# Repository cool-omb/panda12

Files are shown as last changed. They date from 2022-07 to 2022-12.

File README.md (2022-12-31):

# panda12

## 概要 Overview

Bluetooth 接続の 12 キーキーボード。

キーマップの変更等がWiFi経由で出来る。

## 使い方 Usage
### キーボード使用時
スライドスイッチで電源を入れ、 `Test_keyboard` にBluetooth接続する。
### キーマップ設定時
設定ボタンを押しながら電源を入れ、 `Preference_keyboard` にWiFi接続する。
ブラウザからキーマップを変更後、 `保存` ボタンをクリックすることで変更が反映される。

※ 有線LANを接続しているデバイスからは、キーマップ変更ページへ自動で遷移しないことがあるので、 `192.168.4.1` へ手動でアクセスしてください。

## 必要要件 Requirement

- KiCad 6.0.10

  - [Kailh socket MX footprint](https://github.com/daprice/keyswitches.pretty)

- [Arduino IDE 2.0.3](https://www.arduino.cc/en/software)
  - [Arduino core for the ESP32 v2.0.4](https://github.com/espressif/arduino-esp32#installation-instructions)
  - [NimBLE-Arduino v1.4.0](https://github.com/h2zero/NimBLE-Arduino)
  - [ESP32-NimBLE-Keyboard v1.4.0](https://github.com/wakwak-koba/ESP32-NimBLE-Keyboard)
  - [arduino-esp8266fs-plugin v0.5.0](https://github.com/esp8266/arduino-esp8266fs-plugin)
  - [Arduino ESP32 filesystem uploader v1.0](https://github.com/me-no-dev/arduino-esp32fs-plugin)
  - [ESP8266_Spiram](https://github.com/Gianbacchio/ESP8266_Spiram)
  - [ESPAsyncWebServer](https://github.com/me-no-dev/ESPAsyncWebServer)
  - [ArduinoJson](https://github.com/bblanchon/ArduinoJson)

## 注意事項 Note
- BLE通信の安定性は上記のライブラリに依存しており、通信するデバイスによっては動作が不安定になることもございます。
- `Blekeyboard.print()` の挙動が不安定で、これを利用しているテキスト出力もまた安定的に動作しません。

## 参考 Reference

- [CaptivePortalExample](https://github.com/elliotmade/ESP32-Captive-Portal-Example/blob/test/src/main.cpp)

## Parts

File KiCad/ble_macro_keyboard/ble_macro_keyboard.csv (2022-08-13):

Source: | \\wsl.localhost\Ubuntu\home\krkrkrrn\workspace\ble-macro-keyboard\KiCad\ble_macro_keyboard\ble_macro_keyboard.kicad_sch
Date: | 2022/08/08 6:19:14
Tool: | Eeschema (6.0.6)
Generator: | C:\Program Files\KiCad\6.0\bin\scripting\plugins/bom_csv_grouped_by_value.py
Component Count: | 34
Individual Components:
Item | Qty | Reference(s) | Value | LibPart | Footprint | Datasheet | Description | Field4 | Field5 | Field6 | Field7 | Height | MANUFACTURER | Manufacturer_Name | Manufacturer_Part_Number | Mouser Part Number | Mouser Price/Stock | PARTREV
 |  | C1 | 0.01u | Device:C | Capacitor_SMD:C_0603_1608Metric_Pad1.08x0.95mm_HandSolder | ~
 |  | C2 | 0.01u | Device:C | Capacitor_SMD:C_0603_1608Metric_Pad1.08x0.95mm_HandSolder | ~
 |  | C3 | 1u | Device:C | Capacitor_SMD:C_0603_1608Metric_Pad1.08x0.95mm_HandSolder | ~
 |  | C4 | 1u | Device:C | Capacitor_SMD:C_0603_1608Metric_Pad1.08x0.95mm_HandSolder | ~
 |  | C5 | 4.7u | Device:C | Capacitor_THT:CP_Radial_D5.0mm_P2.00mm | ~
 |  | C6 | 10u | Device:C | Capacitor_THT:CP_Radial_D5.0mm_P2.00mm | ~
 |  | D1 | LED | Device:LED | LED_THT:LED_D3.0mm | ~
 |  | D2 | LED_RKBG | Device:LED_RKBG | LED_THT:LED_D5.0mm-4_RGB | ~
 |  | IC1 | ADP3338AKCZ-3.3-RL | ble_keyboard:ADP3338AKCZ-3.3-RL | Ble_keyboard:SOT230P700X180-4N | http://www.analog.com/media/en/technical-documentation/data-sheets/ADP3338.pdf | LDO Voltage Regulator anyCAP 1A SOT223-3 Analog Devices ADP3338AKCZ-3.3-RL, LDO Voltage Regulator, 1.6A, 3.3 V +/-0.8%, 2.7 8 Vin, 3 + Tab-Pin SOT-223 |  |  |  |  | 1.8 |  | Analog Devices | ADP3338AKCZ-3.3-RL | 584-ADP3338AKCZ3.3R | https://www.mouser.co.uk/ProductDetail/Analog-Devices/ADP3338AKCZ-33-RL?qs=WIvQP4zGangPtIg4n%252B1tTA%3D%3D
 |  | J1 | Conn_01x03_Male | Connector:Conn_01x03_Male | Ble_keyboard:JST_SHL_SM03B-SHLS-TF_1x03-1MP_P1.00mm_Horizontal | ~
 |  | Q1 | IRLML6402 | Transistor_FET:IRLML6402 | Package_TO_SOT_SMD:SOT-23 | https://www.infineon.com/dgdl/irlml6402pbf.pdf?fileId=5546d462533600a401535668d5c2263c
 |  | R1 | 10 | Device:R | Resistor_SMD:R_0603_1608Metric_Pad1.05x0.95mm_HandSolder | ~
 |  | R2 | 10 | Device:R | Resistor_SMD:R_0603_1608Metric_Pad1.05x0.95mm_HandSolder | ~
 |  | R3 | 10 | Device:R | Resistor_SMD:R_0603_1608Metric_Pad1.05x0.95mm_HandSolder | ~
 |  | R4 | 47 | Device:R | Resistor_SMD:R_0603_1608Metric_Pad1.05x0.95mm_HandSolder | ~
 |  | R5 | 470 | Device:R | Resistor_SMD:R_0603_1608Metric_Pad1.05x0.95mm_HandSolder | ~
 |  | R6 | 2k | Device:R | Resistor_SMD:R_0603_1608Metric_Pad1.05x0.95mm_HandSolder | ~
 |  | R7 | 100k | Device:R | Resistor_SMD:R_0603_1608Metric_Pad1.05x0.95mm_HandSolder | ~
 |  | SW1 | SW_SPDT | Switch:SW_SPDT | Ble_keyboard:SW_Slide_SPDT_MSK-12C02 | ~
 |  | SW2 | SW_Push | Switch:SW_Push | Ble_keyboard:SW_Push_Dual_x2_TS-4401 | ~
 |  | SW3 | SW_Push | Switch:SW_Push | Keyswitches:Kailh_socket_MX | ~
 |  | SW4 | SW_Push | Switch:SW_Push | Keyswitches:Kailh_socket_MX | ~
 |  | SW5 | SW_Push | Switch:SW_Push | Keyswitches:Kailh_socket_MX | ~
 |  | SW6 | SW_Push | Switch:SW_Push | Keyswitches:Kailh_socket_MX | ~
 |  | SW7 | SW_Push | Switch:SW_Push | Keyswitches:Kailh_socket_MX | ~
 |  | SW8 | SW_Push | Switch:SW_Push | Keyswitches:Kailh_socket_MX | ~
 |  | SW9 | SW_Push | Switch:SW_Push | Keyswitches:Kailh_socket_MX | ~
 |  | SW10 | SW_Push | Switch:SW_Push | Keyswitches:Kailh_socket_MX | ~
 |  | SW11 | SW_Push | Switch:SW_Push | Keyswitches:Kailh_socket_MX | ~
 |  | SW12 | SW_Push | Switch:SW_Push | Keyswitches:Kailh_socket_MX | ~
 |  | SW13 | SW_Push | Switch:SW_Push | Keyswitches:Kailh_socket_MX | ~
 |  | SW14 | SW_Push | Switch:SW_Push | Keyswitches:Kailh_socket_MX | ~
 |  | U1 | MCP73831T-2ACI_OT | ble_keyboard:MCP73831T-2ACI_OT | Ble_keyboard:SOT95P280X145-5N | 56K7045 |  | 1332158 | MCP73831T-2ACI/OT | Microchip | SOT-5
 |  | U2 | ESP32-DEVKITC-32D | ESP32-DEVKITC-32D:ESP32-DEVKITC-32D | Evaluation_board:MODULE_ESP32-DEVKITC-32D |  |  |  |  |  |  |  | Espressif Systems |  |  |  |  | 4
Collated Components:
Item | Qty | Reference(s) | Value | LibPart | Footprint | Datasheet | Description | Field4 | Field5 | Field6 | Field7 | Height | MANUFACTURER | Manufacturer_Name | Manufacturer_Part_Number | Mouser Part Number | Mouser Price/Stock | PARTREV
1 | 2 | C1, C2 | 0.01u | Device:C | Capacitor_SMD:C_0603_1608Metric_Pad1.08x0.95mm_HandSolder | ~
2 | 2 | C3, C4 | 1u | Device:C | Capacitor_SMD:C_0603_1608Metric_Pad1.08x0.95mm_HandSolder | ~
3 | 1 | C5 | 4.7u | Device:C | Capacitor_THT:CP_Radial_D5.0mm_P2.00mm | ~
4 | 1 | C6 | 10u | Device:C | Capacitor_THT:CP_Radial_D5.0mm_P2.00mm | ~
5 | 1 | D1 | LED | Device:LED | LED_THT:LED_D3.0mm | ~
6 | 1 | D2 | LED_RKBG | Device:LED_RKBG | LED_THT:LED_D5.0mm-4_RGB | ~
7 | 1 | IC1 | ADP3338AKCZ-3.3-RL | ble_keyboard:ADP3338AKCZ-3.3-RL | Ble_keyboard:SOT230P700X180-4N | http://www.analog.com/media/en/technical-documentation/data-sheets/ADP3338.pdf | LDO Voltage Regulator anyCAP 1A SOT223-3 Analog Devices ADP3338AKCZ-3.3-RL, LDO Voltage Regulator, 1.6A, 3.3 V +/-0.8%, 2.7 8 Vin, 3 + Tab-Pin SOT-223 |  |  |  |  | 1.8 |  | Analog Devices | ADP3338AKCZ-3.3-RL | 584-ADP3338AKCZ3.3R | https://www.mouser.co.uk/ProductDetail/Analog-Devices/ADP3338AKCZ-33-RL?qs=WIvQP4zGangPtIg4n%252B1tTA%3D%3D
8 | 1 | J1 | Conn_01x03_Male | Connector:Conn_01x03_Male | Ble_keyboard:JST_SHL_SM03B-SHLS-TF_1x03-1MP_P1.00mm_Horizontal | ~
9 | 1 | Q1 | IRLML6402 | Transistor_FET:IRLML6402 | Package_TO_SOT_SMD:SOT-23 | https://www.infineon.com/dgdl/irlml6402pbf.pdf?fileId=5546d462533600a401535668d5c2263c
10 | 3 | R1, R2, R3 | 10 | Device:R | Resistor_SMD:R_0603_1608Metric_Pad1.05x0.95mm_HandSolder | ~
11 | 1 | R4 | 47 | Device:R | Resistor_SMD:R_0603_1608Metric_Pad1.05x0.95mm_HandSolder | ~
12 | 1 | R5 | 470 | Device:R | Resistor_SMD:R_0603_1608Metric_Pad1.05x0.95mm_HandSolder | ~
13 | 1 | R6 | 2k | Device:R | Resistor_SMD:R_0603_1608Metric_Pad1.05x0.95mm_HandSolder | ~
14 | 1 | R7 | 100k | Device:R | Resistor_SMD:R_0603_1608Metric_Pad1.05x0.95mm_HandSolder | ~
15 | 1 | SW1 | SW_SPDT | Switch:SW_SPDT | Ble_keyboard:SW_Slide_SPDT_MSK-12C02 | ~
16 | 1 | SW2 | SW_Push | Switch:SW_Push | Ble_keyboard:SW_Push_Dual_x2_TS-4401 | ~
17 | 12 | SW3, SW4, SW5, SW6, SW7, SW8, SW9, SW10, SW11, SW12, SW13, SW14 | SW_Push | Switch:SW_Push | Keyswitches:Kailh_socket_MX | ~
18 | 1 | U1 | MCP73831T-2ACI_OT | ble_keyboard:MCP73831T-2ACI_OT | Ble_keyboard:SOT95P280X145-5N | 56K7045 |  | 1332158 | MCP73831T-2ACI/OT | Microchip | SOT-5
19 | 1 | U2 | ESP32-DEVKITC-32D | ESP32-DEVKITC-32D:ESP32-DEVKITC-32D | Evaluation_board:MODULE_ESP32-DEVKITC-32D |  |  |  |  |  |  |  | Espressif Systems |  |  |  |  | 4

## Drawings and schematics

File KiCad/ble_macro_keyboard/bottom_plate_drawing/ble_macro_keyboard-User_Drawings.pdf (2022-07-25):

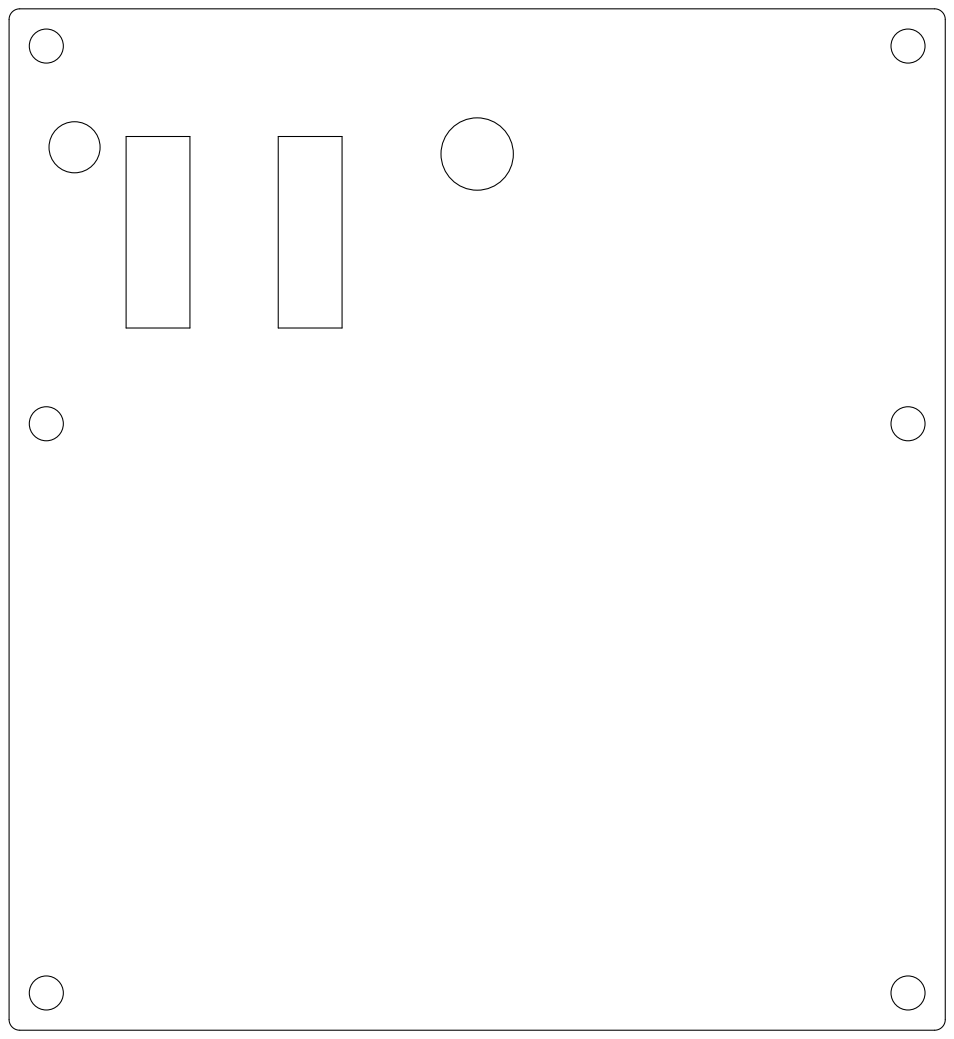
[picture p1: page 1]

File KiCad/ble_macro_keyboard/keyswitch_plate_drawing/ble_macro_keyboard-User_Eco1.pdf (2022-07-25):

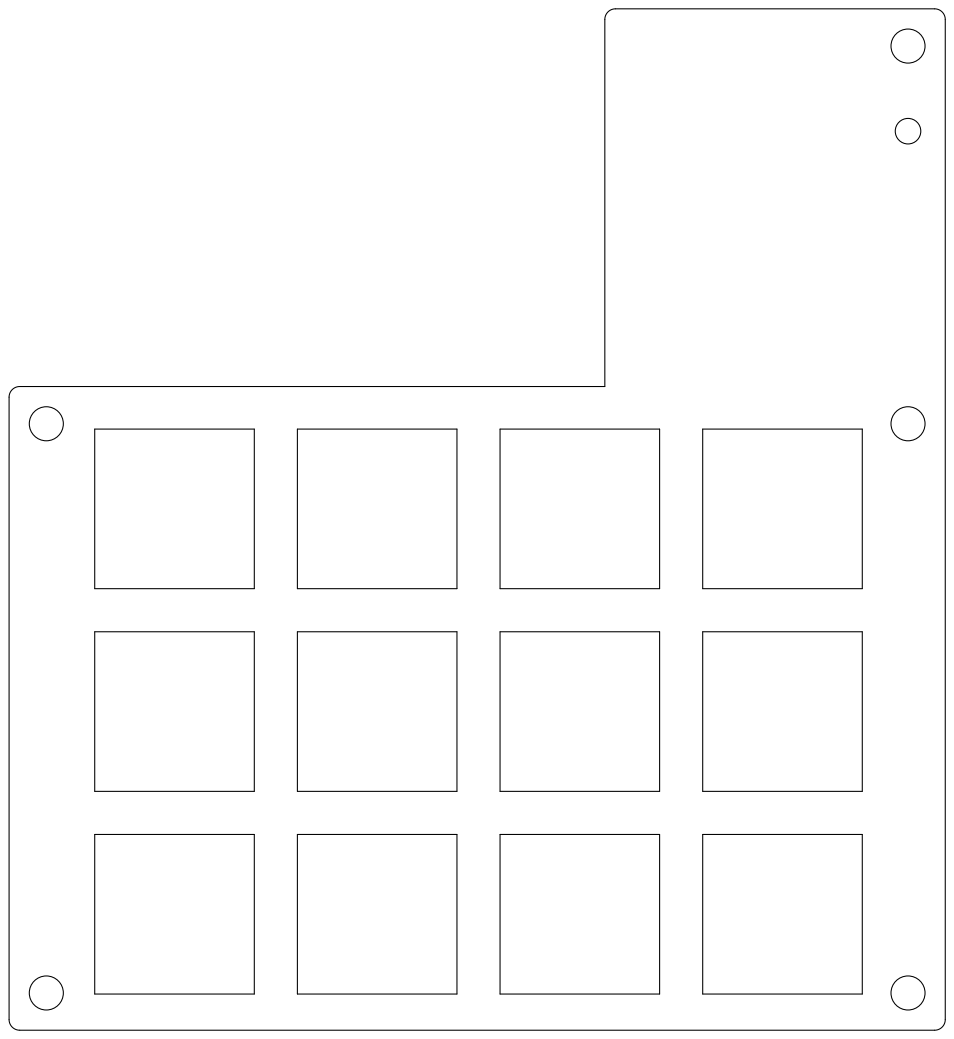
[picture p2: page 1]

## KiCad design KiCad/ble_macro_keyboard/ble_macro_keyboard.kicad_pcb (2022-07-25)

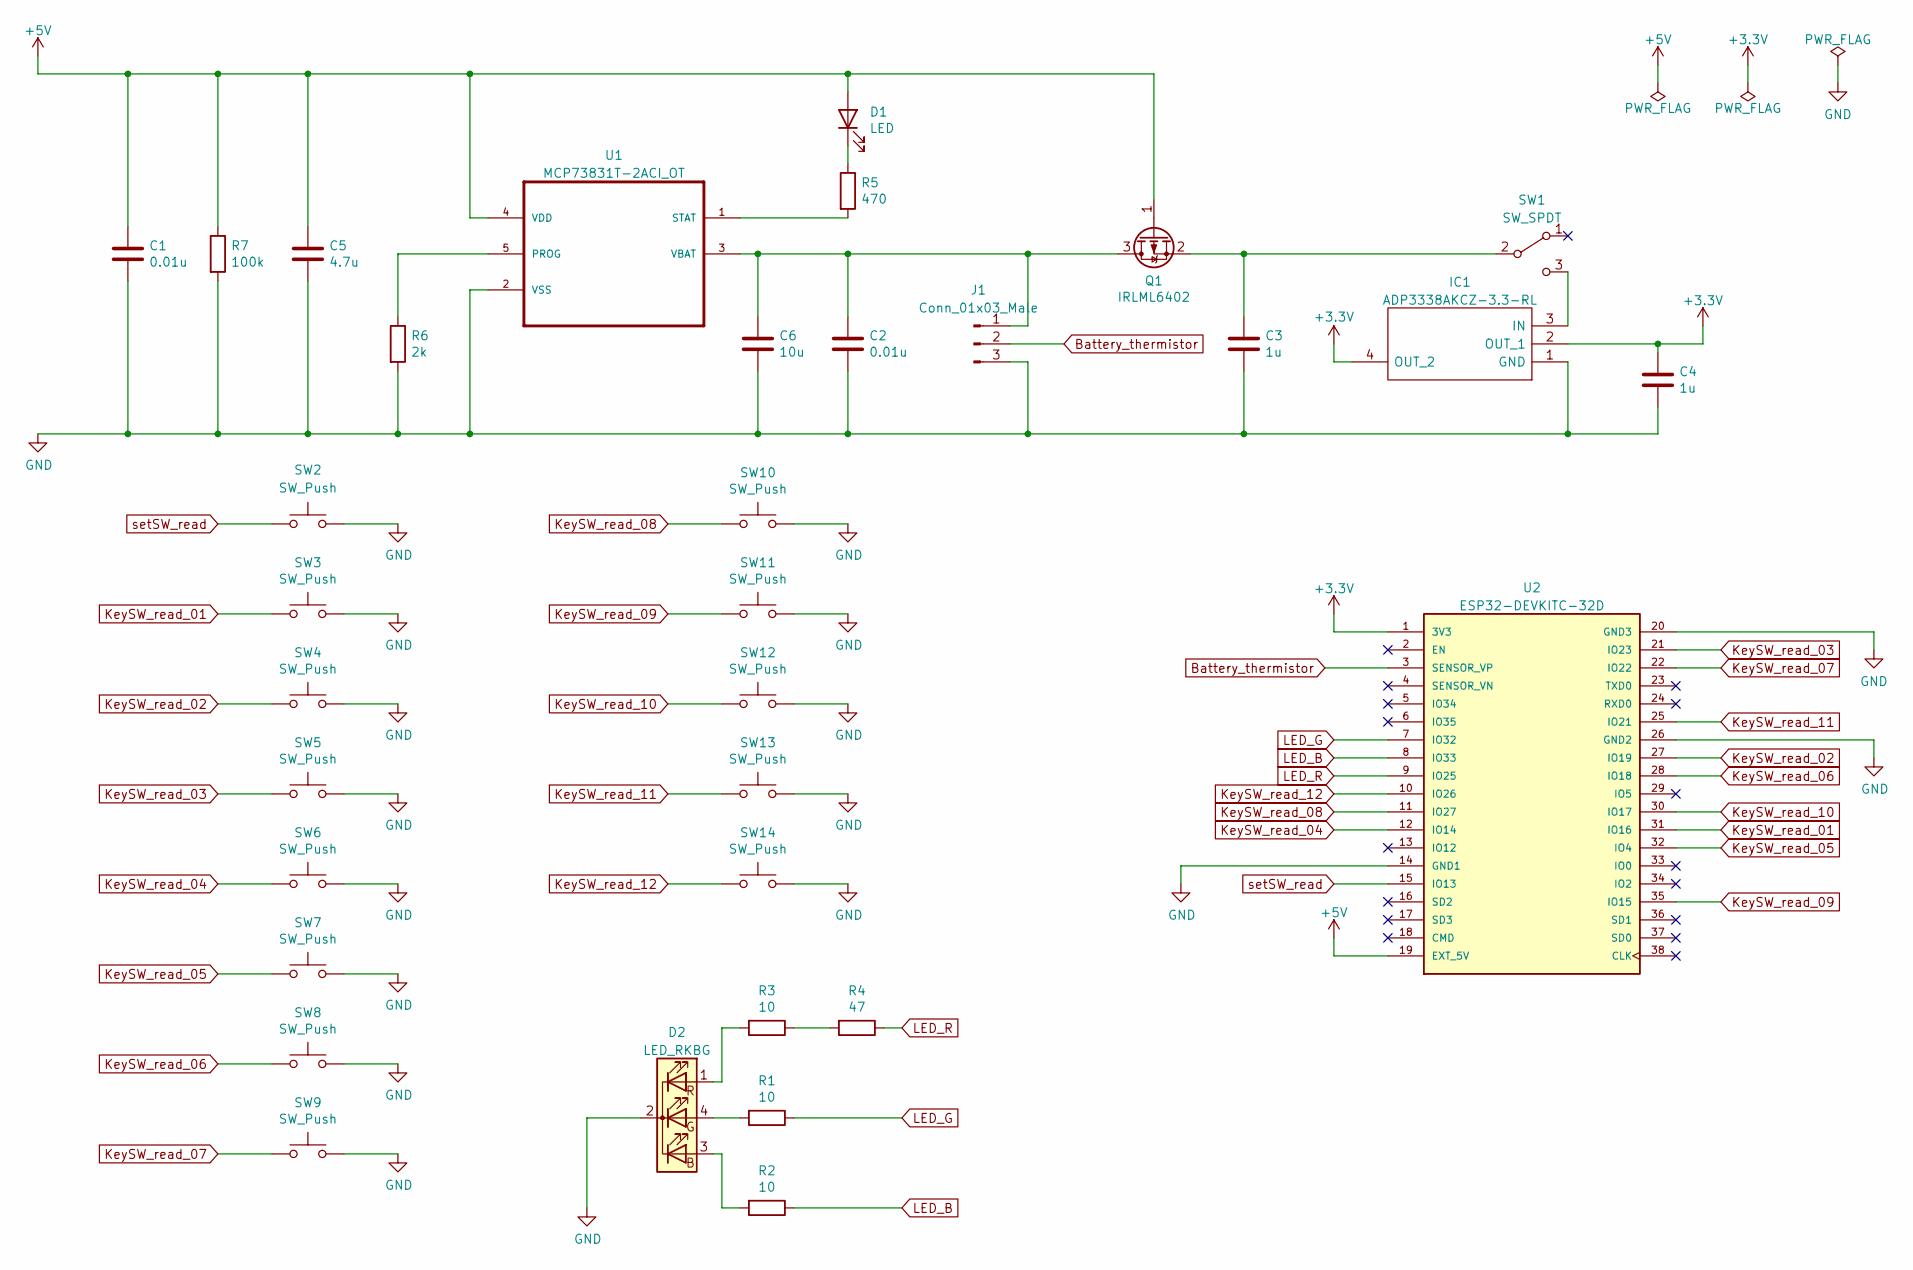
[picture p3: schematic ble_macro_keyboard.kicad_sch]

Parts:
C1, C2: 0.01u; C_0603_1608Metric_Pad1.08x0.95mm_HandSolder
C3, C4: 1u; C_0603_1608Metric_Pad1.08x0.95mm_HandSolder
C5: 4.7u; CP_Radial_D5.0mm_P2.00mm
C6: 10u; CP_Radial_D5.0mm_P2.00mm
D1: LED; LED_D3.0mm
D2: LED_RKBG; LED_D5.0mm-4_RGB
IC1: ADP3338AKCZ-3.3-RL; SOT230P700X180-4N; Mouser Part Number 584-ADP3338AKCZ3.3R
J1: Conn_01x03_Male; JST_SHL_SM03B-SHLS-TF_1x03-1MP_P1.00mm_Horizontal
Q1: IRLML6402; SOT-23
R1, R2, R3: 10; R_0603_1608Metric_Pad1.05x0.95mm_HandSolder
R4: 47; R_0603_1608Metric_Pad1.05x0.95mm_HandSolder
R5: 470; R_0603_1608Metric_Pad1.05x0.95mm_HandSolder
R6: 2k; R_0603_1608Metric_Pad1.05x0.95mm_HandSolder
R7: 100k; R_0603_1608Metric_Pad1.05x0.95mm_HandSolder
SW1: SW_SPDT; SW_Slide_SPDT_MSK-12C02
SW2: SW_Push; SW_Push_Dual_x2_TS-4401
SW3, SW4, SW5, SW6, SW7, SW8, SW9, SW10, SW11, SW12, SW13, SW14: SW_Push; Kailh_socket_MX
U1: MCP73831T-2ACI_OT; SOT95P280X145-5N
U2: ESP32-DEVKITC-32D; MODULE_ESP32-DEVKITC-32D; PARTREV 4

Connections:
+3.3V: C4.1, IC1.2 (OUT_1), IC1.4 (OUT_2), U2.1 (3V3)
+5V: C1.1, C5.1, D1.2 (A), Q1.1 (G), R7.1, U1.4 (VDD), U2.19 (EXT_5V)
Battery_thermistor: J1.2, U2.3 (SENSOR_VP)
GND: C1.2, C2.2, C3.2, C4.2, C5.2, C6.2, D2.2 (K), IC1.1 (GND), J1.3, R6.2, R7.2, SW2.2, SW3.2, SW4.2, SW5.2, SW6.2, SW7.2, SW8.2, SW9.2, SW10.2, SW11.2, SW12.2, SW13.2, SW14.2, U1.2 (VSS), U2.14 (GND1), U2.20 (GND3), U2.26 (GND2)
KeySW_read_01: SW3.1, U2.31 (IO16)
KeySW_read_02: SW4.1, U2.27 (IO19)
KeySW_read_03: SW5.1, U2.21 (IO23)
KeySW_read_04: SW6.1, U2.12 (IO14)
KeySW_read_05: SW7.1, U2.32 (IO4)
KeySW_read_06: SW8.1, U2.28 (IO18)
KeySW_read_07: SW9.1, U2.22 (IO22)
KeySW_read_08: SW10.1, U2.11 (IO27)
KeySW_read_09: SW11.1, U2.35 (IO15)
KeySW_read_10: SW12.1, U2.30 (IO17)
KeySW_read_11: SW13.1, U2.25 (IO21)
KeySW_read_12: SW14.1, U2.10 (IO26)
LED_B: R2.1, U2.8 (IO33)
LED_G: R1.1, U2.7 (IO32)
LED_R: R4.1, U2.9 (IO25)
unnamed: C2.1, C6.1, J1.1, Q1.3 (D), U1.3 (VBAT)
unnamed: C3.1, Q1.2 (S), SW1.2 (B)
unnamed: D1.1 (K), R5.1
unnamed: D2.1 (RA), R3.2
unnamed: D2.3 (BA), R2.2
unnamed: D2.4 (GA), R1.2
unnamed: IC1.3 (IN), SW1.3 (C)
unnamed: R3.1, R4.2
unnamed: R5.2, U1.1 (STAT)
unnamed: R6.1, U1.5 (PROG)
setSW_read: SW2.1, U2.15 (IO13)

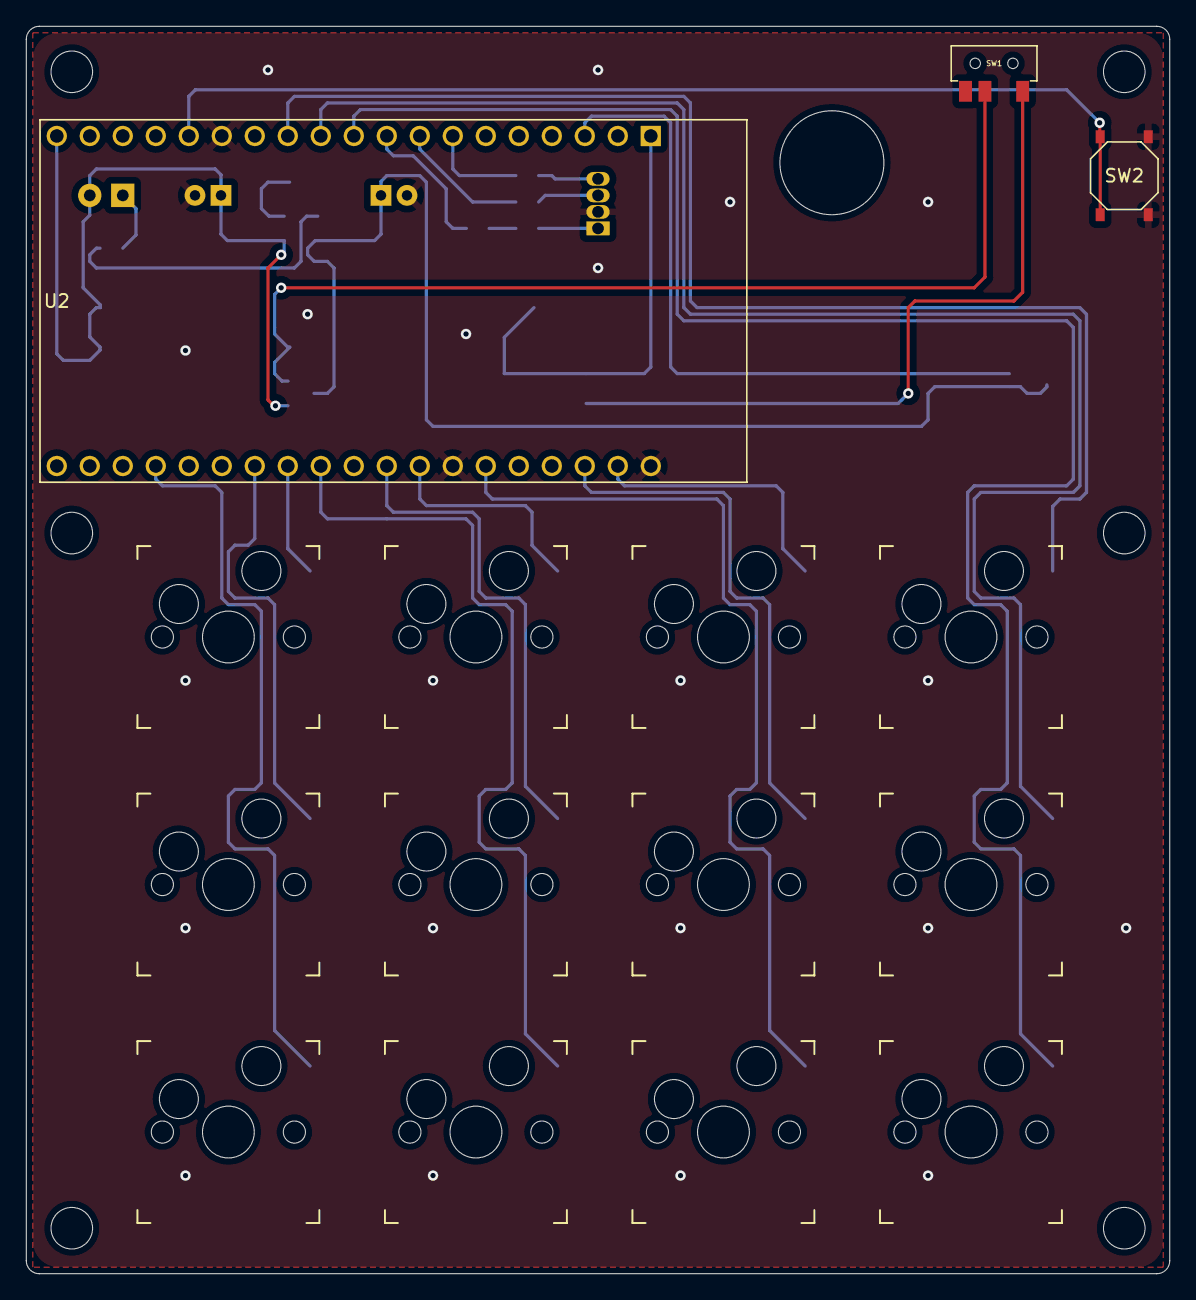
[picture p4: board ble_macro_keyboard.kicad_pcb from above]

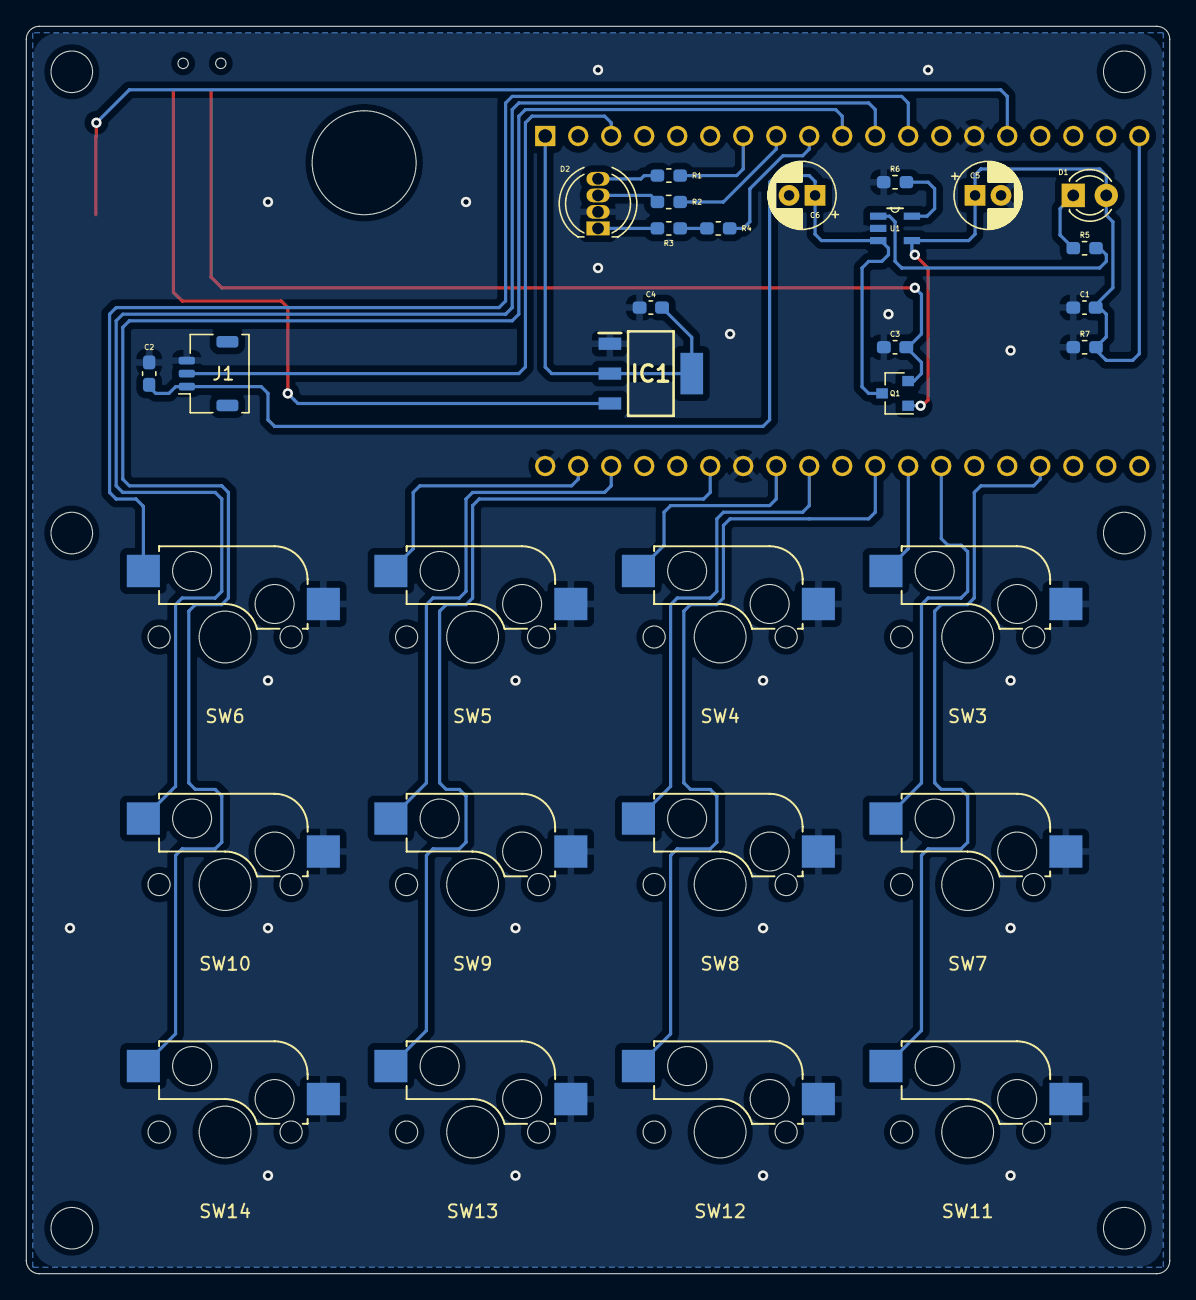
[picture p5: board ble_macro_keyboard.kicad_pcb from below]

Board: 2 copper layers, 88.0 x 96.0 mm, 34 parts (19 on the bottom side), 30 nets.

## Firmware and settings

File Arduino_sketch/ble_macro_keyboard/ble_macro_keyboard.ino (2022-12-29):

#include <Arduino.h>
#include <AsyncTCP.h>
#include "ESPAsyncWebServer.h"
#include "DNSServer.h"
#include <SPIFFS.h>
#include "ArduinoJson.h"
#include <FS.h>
#include <BleKeyboard.h>

using namespace std;

#define LED_R_PIN 25
#define LED_G_PIN 32
#define LED_B_PIN 33
#define LEDC_BASE_FREQ 12800
#define LEDC_RESOLUTION 8
#define LEDC_CHANNEL_R 0
#define LEDC_CHANNEL_G 1
#define LEDC_CHANNEL_B 2


#define PREFERENCE_SW_PIN 13
#define DEFAULT_DEVICE_NAME "Test_Keyboard"
#define DEFAULT_DEVICE_MANUFACTURER "Panda12_manufacturer"

bool isConfig = false;
const vector<int> SW_PINS{16, 19, 23, 14, 4, 18, 22, 27, 15, 17, 21, 26};

const char *SSID = "Preference_Keyboard";

int LAYER_LENGTH = -1;
int OUTPUT_LENGTH = -1;
int INPUT_LENGTH = -1;
int INTERVAL_MS = 100;
int IS_LED_ON = 0;
int LED_R_BRIGHTNESS = 0;
int LED_G_BRIGHTNESS = 0;
int LED_B_BRIGHTNESS = 0;

AsyncWebServer server(80);
DNSServer dnsServer;

BleKeyboard bleKeyboard(DEFAULT_DEVICE_NAME, DEFAULT_DEVICE_MANUFACTURER, 100);
DynamicJsonDocument preferenceDocument(65536);

void handleUpload(AsyncWebServerRequest *request, String filename, size_t index, uint8_t *data, size_t len, bool final){
  // if (!index) {
  //     request->_tempFile = SPIFFS.open("/" + filename, "w");
  // }
  // if (len) {
  //     request->_tempFile.write(data, len);
  // }
  // if (final) {
  //     request->_tempFile.close();
  //     request->send(200, "text/plain", "filename: "+String(filename));
  // }
}

void handleBody(AsyncWebServerRequest *request, uint8_t *data, size_t len, size_t index, size_t total){
  if(!index){
    // Serial.printf("BodyStart: %u B\n", total);
    request->_tempFile = SPIFFS.open("/keymap.json", "w");
  }
  request->_tempFile.write(data, len);
  // Serial.printf("%s", (const char*)data);
  if(index + len == total){
    request->_tempFile.close();
    request->send(200, "text/plain", "Write keymap.json success.");
    // Serial.printf("BodyEnd: %u B\n", total);
  }
}

void webServerSetup()
{
  server.serveStatic("/", SPIFFS, "/").setDefaultFile("index.html");
  server.on(
    "/post",
    HTTP_POST,
    [](AsyncWebServerRequest* request){
      request->send(200, "text/plain", "keymap.json posted.");
    },
    handleUpload,
    handleBody
  );

  server.onNotFound([](AsyncWebServerRequest *request)
  {
    String redirectUrl = "http://";
    redirectUrl += WiFi.softAPIP().toString();
    redirectUrl += "/";
    request->redirect(redirectUrl);
  });

  server.begin();
}


void setupLed() {
  if(IS_LED_ON) {
    ledcSetup(LEDC_CHANNEL_R, LEDC_BASE_FREQ, LEDC_RESOLUTION);
    ledcAttachPin(LED_R_PIN, LEDC_CHANNEL_R);
    ledcWrite(LEDC_CHANNEL_R, LED_R_BRIGHTNESS);
    ledcSetup(LEDC_CHANNEL_G, LEDC_BASE_FREQ, LEDC_RESOLUTION);
    ledcAttachPin(LED_G_PIN, LEDC_CHANNEL_G);
    ledcWrite(LEDC_CHANNEL_G, LED_G_BRIGHTNESS);
    ledcSetup(LEDC_CHANNEL_B, LEDC_BASE_FREQ, LEDC_RESOLUTION);
    ledcAttachPin(LED_B_PIN, LEDC_CHANNEL_B);
    ledcWrite(LEDC_CHANNEL_B, LED_B_BRIGHTNESS);
  }
}

void setupPinMode() {
  pinMode(PREFERENCE_SW_PIN, INPUT_PULLUP);
  for(int pin : SW_PINS) {
    pinMode(pin, INPUT_PULLUP);
  }
}

void setupPreferenceMode() {
  WiFi.softAP(SSID);
  dnsServer.start(53, "*", WiFi.softAPIP());
  webServerSetup();
}

void setupKeyboardMode() {
  File file = SPIFFS.open("/keymap.json", "r");
  DeserializationError error = deserializeJson(preferenceDocument, file);
  if (error) {
    // Serial.println(F("Error: deserializeJson"));
    // Serial.println(error.c_str());
  }
  JsonObject root = preferenceDocument.as<JsonObject>();

  // Serial.println(preferenceDocument["version"].as<String>());
  // Serial.println(preferenceDocument["layout"][0].as<String>());
  file.close();

  LAYER_LENGTH = preferenceDocument["length"]["layer"].as<int>();
  OUTPUT_LENGTH = preferenceDocument["length"]["output"].as<int>();
  INPUT_LENGTH = preferenceDocument["length"]["input"].as<int>();
  INTERVAL_MS = preferenceDocument["preference"]["interval"].as<int>();
  IS_LED_ON = preferenceDocument["preference"]["ledOn"].as<int>();
  LED_R_BRIGHTNESS = preferenceDocument["preference"]["ledRed"].as<int>();
  LED_G_BRIGHTNESS = preferenceDocument["preference"]["ledGreen"].as<int>();
  LED_B_BRIGHTNESS = preferenceDocument["preference"]["ledBlue"].as<int>();

  setupLed();

  delay(20);
  // Serial.println(INPUT_LENGTH);
  bleKeyboard.begin();
  delay(100);
}

unsigned int readAllPushedBit() {
  unsigned int pushed = 0;
  for(int i = 0; i < (int)SW_PINS.size(); ++ i) {
    if(digitalRead(SW_PINS[i]) == LOW) {
      pushed |= (1<<i);
    }
  }
  return pushed;
}

int getKeyNumber(int layerIndex, int outputIndex, int inputIndex) {
  return preferenceDocument["assign"][layerIndex][outputIndex][inputIndex]["num"].as<int>();
}

String getKeyText(int layerIndex, int outputIndex, int inputIndex) {
  return preferenceDocument["assign"][layerIndex][outputIndex][inputIndex]["text"].as<String>();
}

void loopKeyboard() {
  // static variable defind.
  static unsigned int swPushedBit = 0;
  static int layerIndex = 0;

  // measures for chattering.
  if(swPushedBit != readAllPushedBit()) {
    delay(10);
    if(bleKeyboard.isConnected()) {
      unsigned int currentSwPushedBit = readAllPushedBit();
      unsigned int xorSwPushedBit = currentSwPushedBit ^ swPushedBit;

      int currentLayerIndex = 0;
      for(int i = 0; i < INPUT_LENGTH; ++i) {
        if(currentSwPushedBit & (1<<i)) {
          if(getKeyNumber(0, 0 , i) >= 256) {
            currentLayerIndex += getKeyNumber(0, 0 , i) - 256;
          }
          
        }
      }
      if(layerIndex != currentLayerIndex) {
        bleKeyboard.releaseAll();
        for(int i = 0; i < INPUT_LENGTH; ++i) {
          if (currentSwPushedBit & (1<<i)) {
            int keyNumber = getKeyNumber(currentLayerIndex, 0, i);
            if (keyNumber < 0) {
              // Serial.println(getKeyText(currentLayerIndex, 0, i));
              bleKeyboard.print(getKeyText(currentLayerIndex, 0, i));
            } else if (keyNumber < 256) {
              // Serial.println(keyNumber);
              bleKeyboard.press(keyNumber);
            }
          }
        }
        layerIndex = currentLayerIndex;
      } else {
        for(int i = 0; i < (int)SW_PINS.size(); ++i) {
          if(xorSwPushedBit & (1<<i)) {
            int keyNumber = getKeyNumber(currentLayerIndex, 0, i);
            if(currentSwPushedBit & (1<<i)) {
              if (keyNumber < 0) {
                // Serial.println(getKeyText(currentLayerIndex, 0, i));
                bleKeyboard.print(getKeyText(currentLayerIndex, 0, i));
              } else if (keyNumber < 256) {
                // Serial.println(keyNumber);
                bleKeyboard.press(keyNumber);
              }
            } else {
              if(0 <= keyNumber && keyNumber < 256) {
                bleKeyboard.release(keyNumber);
              }
            }
          }
        }
      }
      swPushedBit = currentSwPushedBit;
    }
  }
  delay(INTERVAL_MS);
}

void setup()
{
  setupLed();

  // Serial.begin(115200);

  SPIFFS.begin();

  setupPinMode();
  if (digitalRead(PREFERENCE_SW_PIN) == LOW) {
    isConfig = true;
    setupPreferenceMode();
  } else {
    setupKeyboardMode();
  }
}

void loop()
{
  if (isConfig) {
    dnsServer.processNextRequest();
  } else {
    loopKeyboard();
  }
}

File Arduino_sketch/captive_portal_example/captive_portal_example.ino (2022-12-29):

#include <DNSServer.h>
#ifdef ESP32
#include <WiFi.h>
#include <AsyncTCP.h>
#elif defined(ESP8266)
#include <ESP8266WiFi.h>
#include <ESPAsyncTCP.h>
#endif
#include "ESPAsyncWebServer.h"
#include <SPIFFS.h>
#include "AsyncJson.h"
#include "ArduinoJson.h"

DNSServer dnsServer;
AsyncWebServer server(80);

class CaptiveRequestHandler : public AsyncWebHandler {
public:
    CaptiveRequestHandler() {}
    virtual ~CaptiveRequestHandler() {}

    bool canHandle(AsyncWebServerRequest *request){
        //request->addInterestingHeader("ANY");
        return true;
    }

    void handleRequest(AsyncWebServerRequest *request) {
        request->send(SPIFFS, "/index.html", "text/html");
    }
};


void webServerSetup()
{
    // server.addHandler(new CaptiveRequestHandler()).setFilter(ON_AP_FILTER);

    AsyncCallbackJsonWebHandler* jsonHandler = new AsyncCallbackJsonWebHandler(
        "/keymap.json", [](AsyncWebServerRequest *request, JsonVariant &json
        ) {
        // JsonObject jsonObject = json.as<JsonObject>();
        Serial.println("Call AsyncCallbackJsonWebHandler.");
        request->send(200, "application/json", "{test: \"ok\"}");
        }
    );
    server.addHandler(jsonHandler);

    server.serveStatic("/", SPIFFS, "/").setDefaultFile("index.html");
    
    // server.on("/keymap.json", HTTP_POST, [](AsyncWebServerRequest* request) {
        // AsyncWebServerResponse* response = request->beginResponse(200, "text/html", "hello world");
        // response->addHeader("Connection", "close");
        // request->send(response);
    //   }, handleUpload);

    // server.onFileUpload(handleUpload);

    server.begin();
}

void setup(){
    Serial.begin(115200);
    SPIFFS.begin();
    WiFi.softAP("esp-captive");
    dnsServer.start(53, "*", WiFi.softAPIP());
    webServerSetup();
}

void loop(){
    dnsServer.processNextRequest();   
}

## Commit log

2021-06-18 add requirement
    [ble_macro_keyboard.kicad_pcb, ble_macro_keyboard.sch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]
2022-06-14 プレゼン向けキー配置
2022-07-10 replace KiCADv6 and new version circuit diagram.
    [ble_macro_keyboard.kicad_sch]
2022-07-10 library replace and connect symbol to footprint.
    [ble_macro_keyboard.kicad_sch]
2022-07-12 keyswitch add to 12.
    [ble_macro_keyboard.kicad_sch]
2022-07-22 ライブラリを相対パスへ変更
2022-07-22 コネクタを除き、シンボルとフットプリントの紐づけ完了
    [ble_macro_keyboard.kicad_sch]
2022-07-22 JST SHコネクタ 3pin のフットプリント作成
2022-07-22 git submodule削除
    [ble_macro_keyboard.kicad_sch]
2022-07-24 基板図配線のためにマイコンのピン入れ替え
    [ble_macro_keyboard.kicad_pcb, ble_macro_keyboard.kicad_sch]
2022-07-24 リファレンス指定子を昇順に変更
    [ble_macro_keyboard.kicad_pcb, ble_macro_keyboard.kicad_sch]
2022-07-24 シルクスクリーンのリファレンス指定子の印字位置を内側に変更
    [ble_macro_keyboard.kicad_pcb]
2022-07-24 [fix] Vsysラベルを3.3vへ修正
    [ble_macro_keyboard.kicad_pcb, ble_macro_keyboard.kicad_sch]
2022-07-25 [update] GND以外パターン接続
    [ble_macro_keyboard.kicad_pcb, ble_macro_keyboard.kicad_sch]
2022-07-25 [add] ライブラリ及び回路図にNPTH_8mmを追加
    [ble_macro_keyboard.kicad_pcb]
2022-07-25 [fix] Ble_keyboardフットプリントライブラリのSWがGNDに接続するように解決
    [ble_macro_keyboard.kicad_pcb, ble_macro_keyboard.kicad_sch]
2022-07-25 [fix] Ble_keyboardライブラリのシルクスクリーンとパッドが干渉するライブラリを修正
    [ble_macro_keyboard.kicad_pcb]
2022-07-25 [add] 底板の図面出力
    [ble_macro_keyboard-User_Drawings.dxf, ble_macro_keyboard.kicad_pcb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]
2022-07-25 [add] キースイッチプレートの図面出力
    [ble_macro_keyboard-User_Drawings.dxf, ble_macro_keyboard.kicad_pcb]
2022-07-25 [fix] ハンダマスクの最小幅を0に設定
    [ble_macro_keyboard.kicad_pcb]
2022-07-25 [fix] キースイッチプレートの角をフィレット
    [ble_macro_keyboard-User_Drawings.dxf, ble_macro_keyboard.kicad_pcb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]
2022-07-25 [fix] 底板および基板外形の角をフィレット
    [ble_macro_keyboard-User_Drawings.dxf, ble_macro_keyboard.kicad_pcb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]
2022-07-25 [add] 基盤製造用ファイルの出力
    [ble_macro_keyboard.kicad_pcb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]
2022-07-25 [fix] Elecrow発注用にgerberファイル名変更
    [ble_macro_keyboard_bottom_plate.dxf, ble_macro_keyboard_bottom_plate.kicad_pcb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]
2022-07-25 [fix] User.drawingsレイヤーに底板のアクリルプレート、User.Eco1にキースイッチプレートのアクリルの図面を設定
    [ble_macro_keyboard-User_Drawings.dxf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]
2022-08-02 ignore KiCAD backups
2022-08-02 KiCAD cache file ignore
2022-08-02 [fix] KiCADのキャッシュを除外
2022-08-06 [update] 12鍵マクロキーのピン配置に対応
2022-08-08 [fix] ピン配置の宣言をvectorに変更
    [ble_macro_keyboard.csv]
2022-08-09 [update] EEPROM 読み書きの検証
2022-08-10 [refactor] 変数名の整理
2022-08-10 [refactor] SETTING_SW を keymaps から分離
2022-08-10 [add] キーマップのレイヤー追加
2022-08-10 [fix] Builtin LED delete.
    [ble_macro_keyboard.ino]
2022-08-10 [update] device value load rom
2022-08-11 if to switch
2022-08-13 [add] led config add.
2022-08-13 [doc] Readme 必要要件更新
2022-12-26 [add] Pull ISLT65 repo
    Arduino sketch for wifi key preference.
2022-12-29 [add] Write json esp32 flash
    POST body to SPIFFS write.
